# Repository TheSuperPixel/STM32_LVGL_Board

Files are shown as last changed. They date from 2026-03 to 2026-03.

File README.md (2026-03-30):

# STM32H750屏幕一体板
## 简介
这是我在2025年3月做的一个STM32H750屏幕一体开发板，板载SDRAM，QSPI FLASH，SD卡，DAP-LINK，LCD屏幕，OV5640摄像头。板子参考反客科技设计，可运行LVGL等多种图形化界面系统。

在2024学习完嵌入式Linux和FPGA后，我一直好奇板子的硬件电路结构和硬件设计，在好奇心的和网上各位开源大佬工程的熏陶下，我开始学习高速电路设计与layout。通过观看教程 我学习了高速PCB的设计技巧，BGA芯片的封装的扇孔布线技巧，传输线和计算阻抗匹配方法，蛇形等长和差分等长的绘制技巧，电源铺铜技巧，了解了电源拓扑，DDR拓扑结构和EMC电磁兼容的大致内容，板子制作过程碰到了很多困难，USB忘记串接电阻，LCD接口画反，错把无源晶振当有源晶振焊接造成电源短路，FLASH芯片型号选错，二极管封装画反等问题接连出现，在不断调整和改进下，板子的外设和LVGL终于全部跑通了！
## 演示视频
https://www.bilibili.com/video/BV1wXQhY8ENJ

## 使用方法
### 屏幕一体板v1 文件夹
第1版屏幕一体板的AD工程，已打板测试，阻抗不限，测试时在捷配进行打板<br>
此版本有LCD接口画反、USB信号线忘记上拉电阻导致无法通信、FLASH 芯片封装错误等问题，不建议使用。

### 屏幕一体板v2 文件夹
第2版屏幕一体板的AD工程，已打板测试，阻抗不限，测试时在捷配进行打板<br>
此版本改进上一版的问题，在焊接的时候因为在有源晶振位置错焊无源晶振，导致板子短路。后续重装主芯片和SDRAM后开始出现SDRAM读写失败的问题。此版本未经过充分测试，不建议使用。

### 屏幕一体板v3 文件夹
第3版屏幕一体板的AD工程，已打板测试，阻抗不限，测试时在捷配进行打板<br>
此版本在上一版的基础上，独立了各个外设电路的电源域，通过0欧姆电阻相连。后续发现3.3V电源不稳，导致有概率无法和电脑进行USB通信。经过排查初步判断因为输入的5V电源的滤波电容不够引起的。

### 测试例程
存放着测试例程代码，主要来自反客科技资料

### 其他资料
存放着DAP-LINK固件(推荐使用串口烧录)、调试时记录的《STM32H750屏幕一体板调试笔记》

## 主要参考资料
1.反客科技STM32H750XBH6板子 https://www.taobao.com/list/dianpu/212360197.htm<br>
2.CMSIS DAP LINK设计 https://oshwhub.com/Southerly/daplink-fang-zhen-qi-swd

## 注意事项
1.请严格遵守开源协议，若需要转载分享仓库内容，请注明来源。不得擅自将本设计用于商业用途。<br>
2.本项目仅供个人研究、学习与交流。元器件、封装、原理图和PCB设计等已根据数据手册重新校验或绘制。若您认为本项目中不慎包含了侵犯您版权的内容，请及时联系，我将第一时间予以处理。

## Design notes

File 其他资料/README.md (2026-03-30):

# 第三方资料声明

## 来源说明
CMSIS_DAP.hex文件来自 https://oshwhub.com/Southerly/daplink-fang-zhen-qi-swd

## 版权与协议 (Copyright & License)
* **版权归属：** 版权归原作者所有。
* **引用目的：** 本项目仅将其作为硬件验证的参考驱动使用。

## 免责声明
本项目作者 (TheSuperPixel) 不对本目录下的文件质量、稳定性或潜在侵权风险负责。

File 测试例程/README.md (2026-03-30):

# Third-Party Source Notice (第三方代码声明)
LVGL例程_基于800x480分辨率_窗口控件演示

## 来源说明
本目录下的代码及工程文件（包括但不限于底层驱动、寄存器配置、初始化脚本）由 **反客科技** 提供。

## 版权与协议
* **版权归属：** 版权归原作者所有。
* **引用目的：** 本项目仅将其作为硬件验证的参考驱动使用。

## 免责声明
本项目作者 (TheSuperPixel) 不对本目录下的代码质量、稳定性或潜在侵权风险负责。

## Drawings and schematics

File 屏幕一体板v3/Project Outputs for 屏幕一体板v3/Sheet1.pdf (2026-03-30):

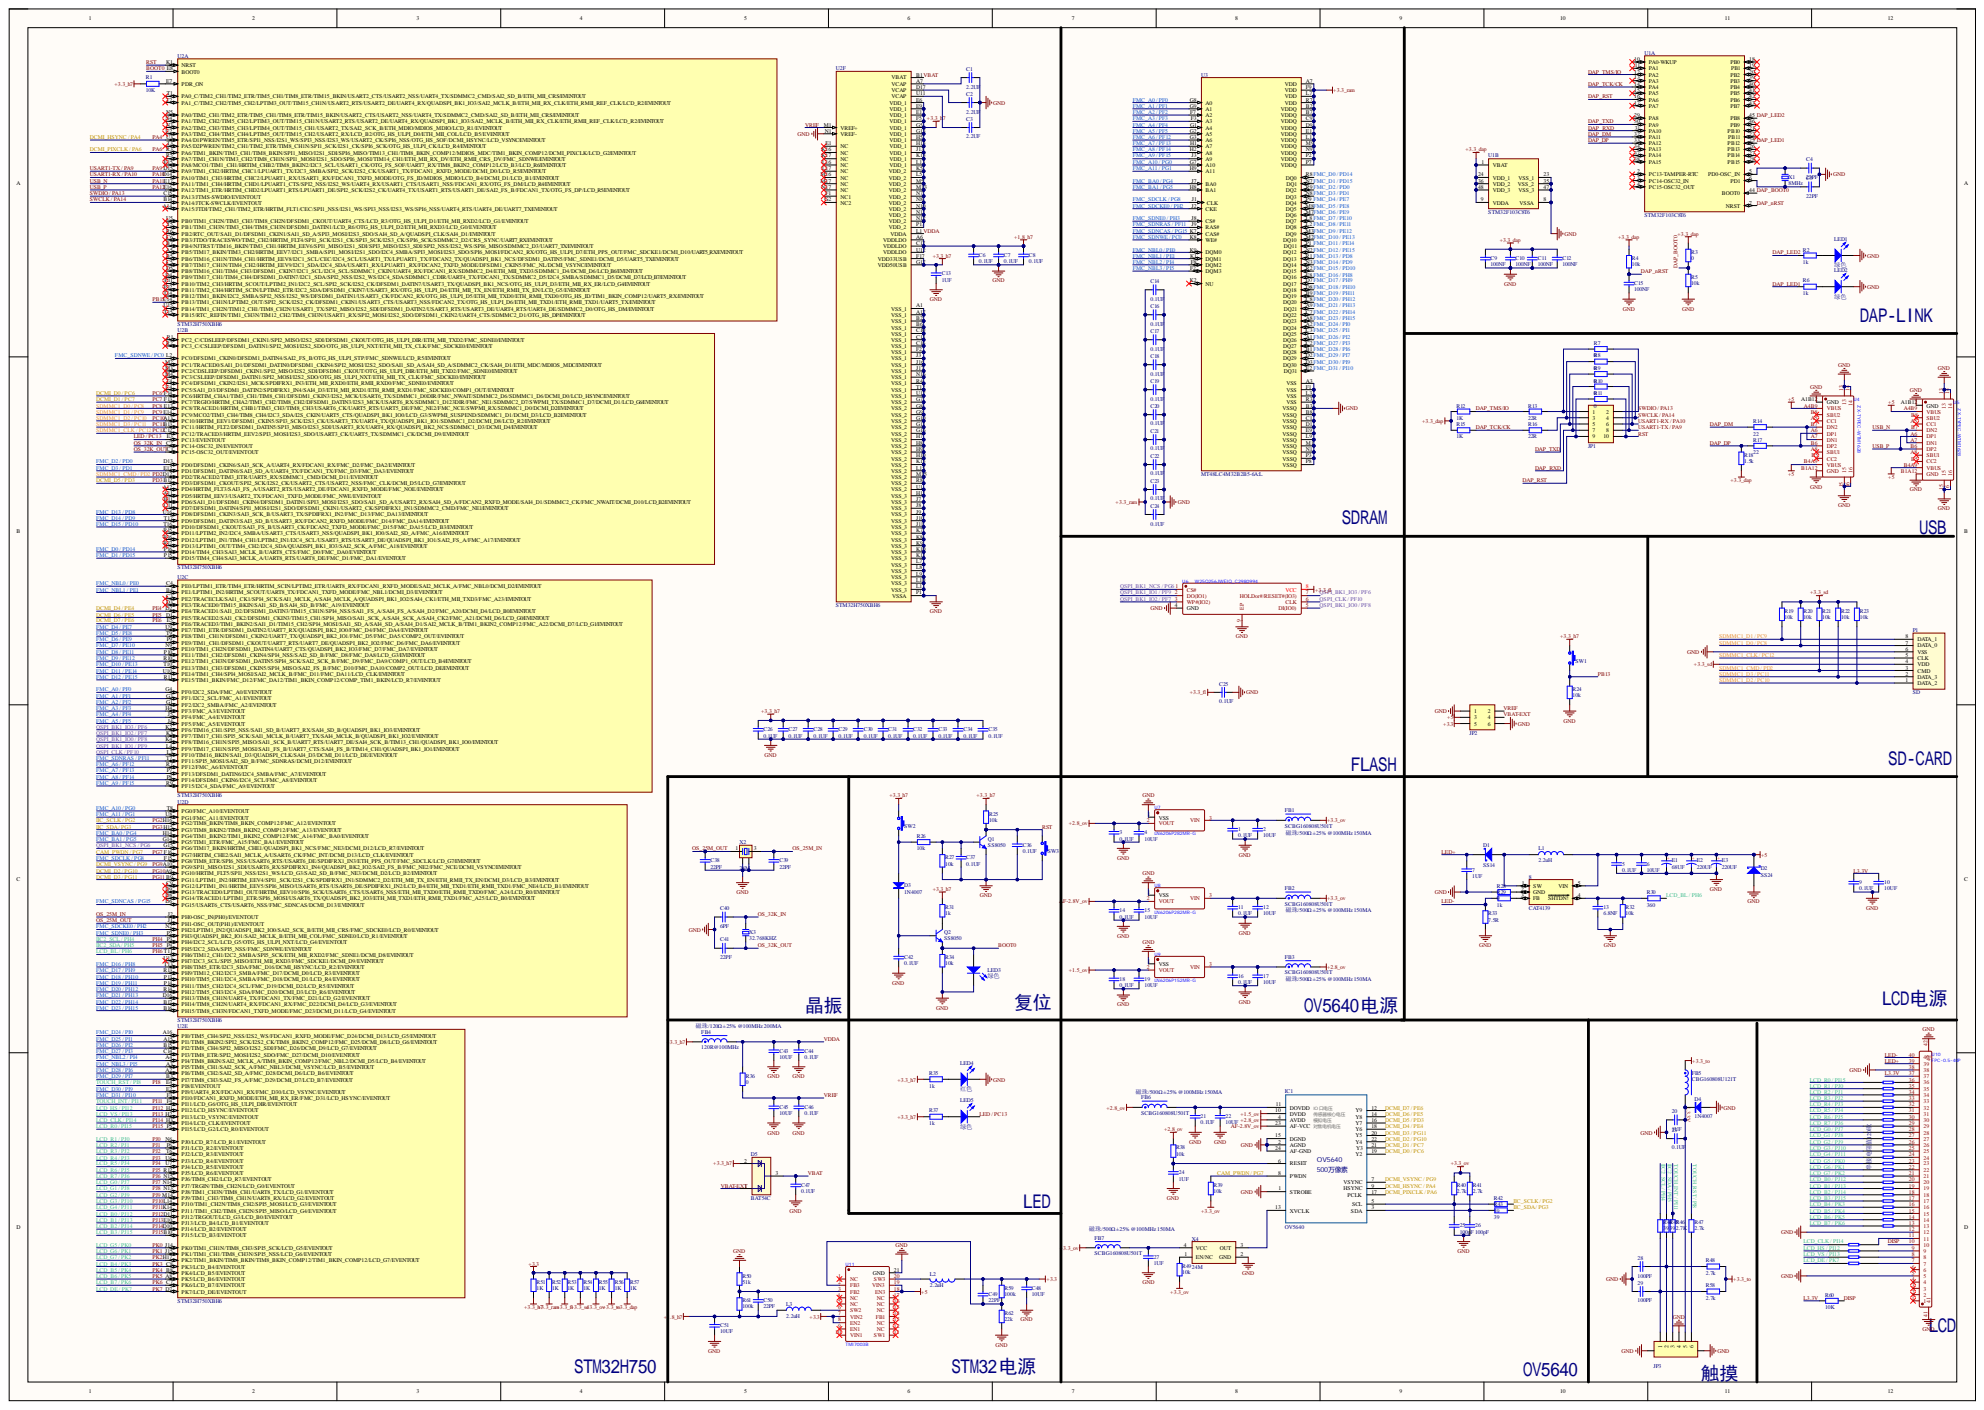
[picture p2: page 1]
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

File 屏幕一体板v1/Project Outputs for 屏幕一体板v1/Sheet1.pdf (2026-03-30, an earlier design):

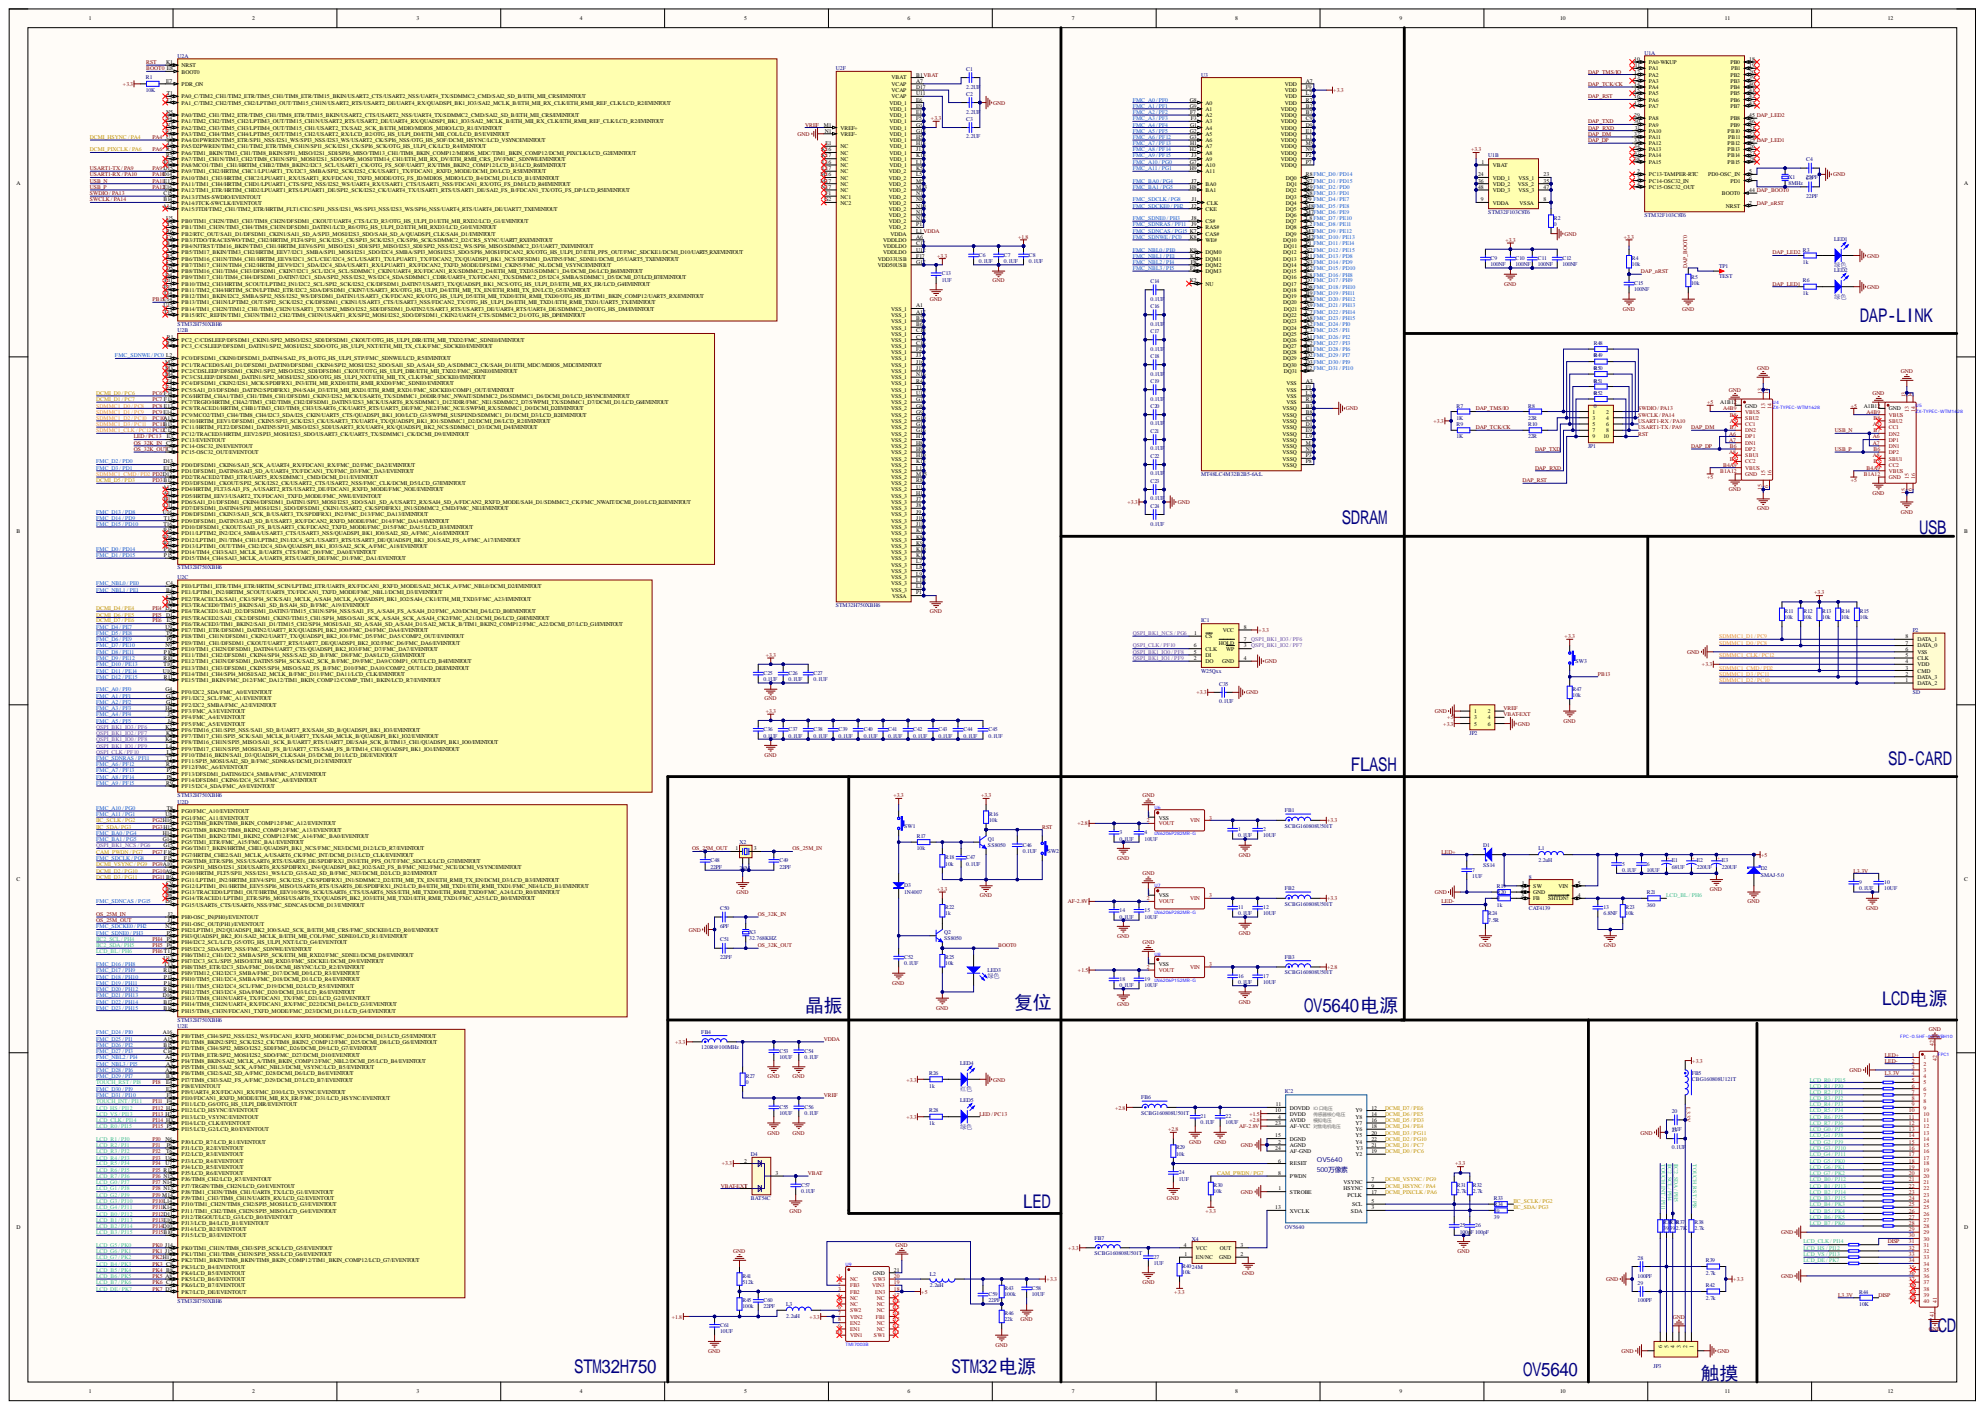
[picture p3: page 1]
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

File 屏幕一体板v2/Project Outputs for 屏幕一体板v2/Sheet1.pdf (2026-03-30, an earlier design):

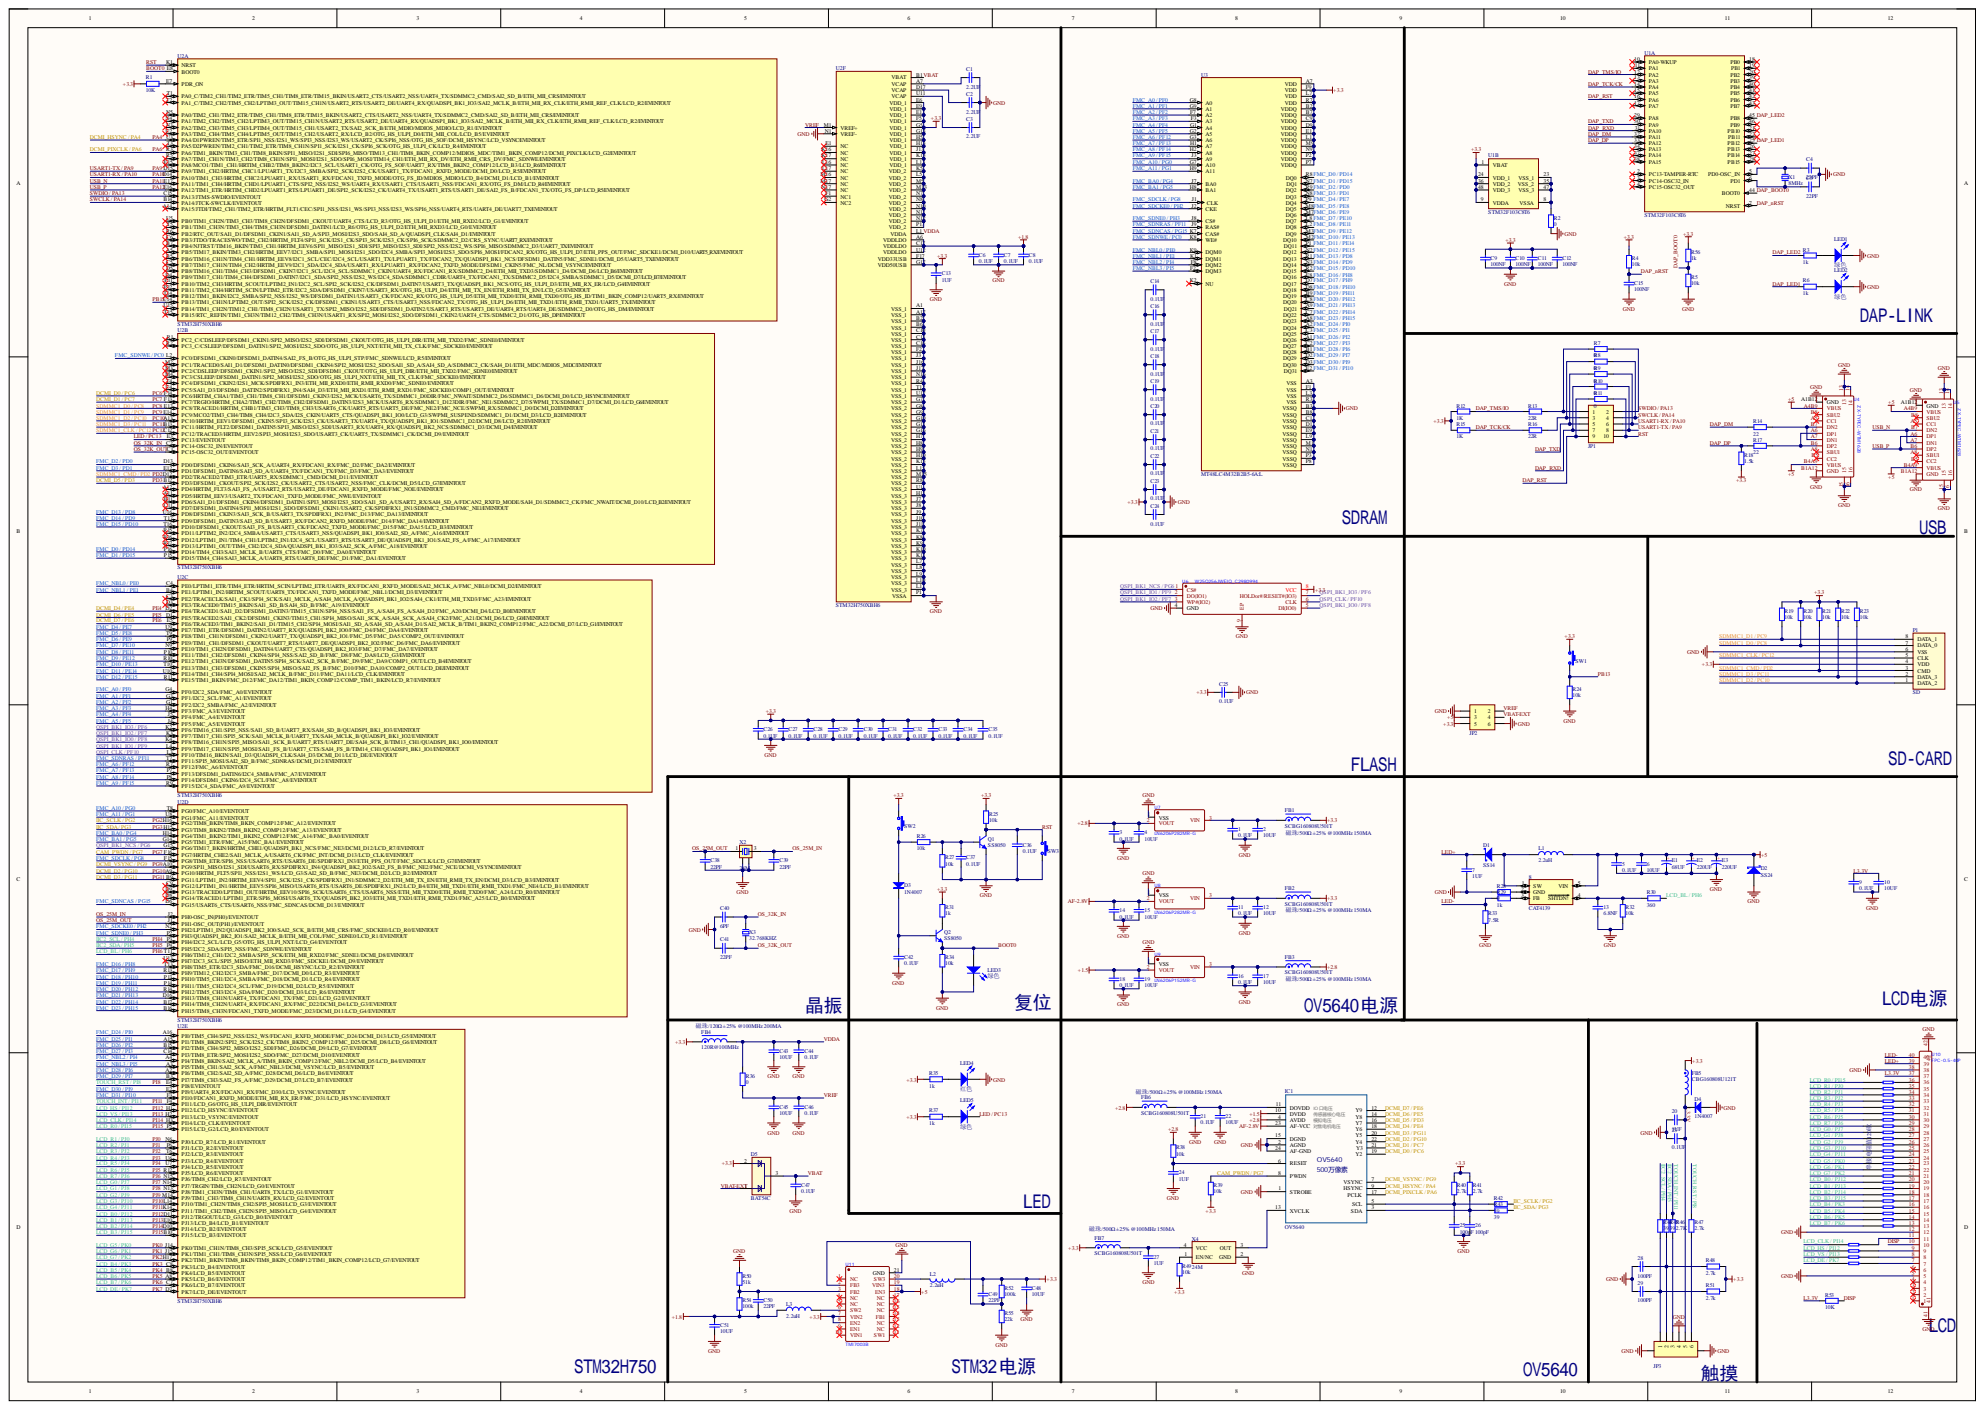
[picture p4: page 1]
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

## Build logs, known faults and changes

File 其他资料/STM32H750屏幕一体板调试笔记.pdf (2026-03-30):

# 屏幕一体板焊接和调试

## 2025.3 月左右完成

# 1.3.3V 短路问题

1.2.28 日，第一次打板，发现 3.3V 短路
原因：背面的去耦电容是 0201 封装，但是焊接了 0402 封装造成连锡

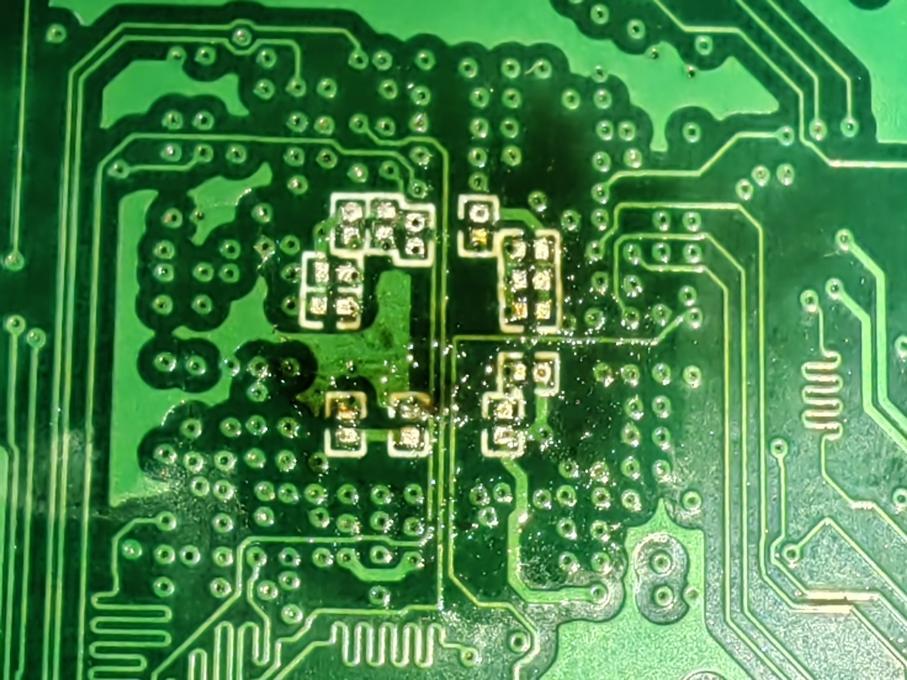
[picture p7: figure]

## 2.FLASH 芯片读写错误问题

2.2.28 日，第一次打板，发现 FLASH 芯片读写错误

## 原因：把 W25Q256 买成了 W25Q32

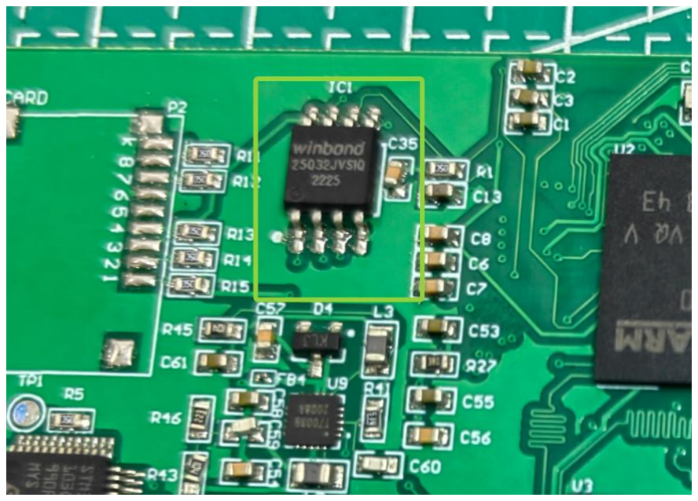
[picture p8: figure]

## 3.电脑无法连接 USB 问题

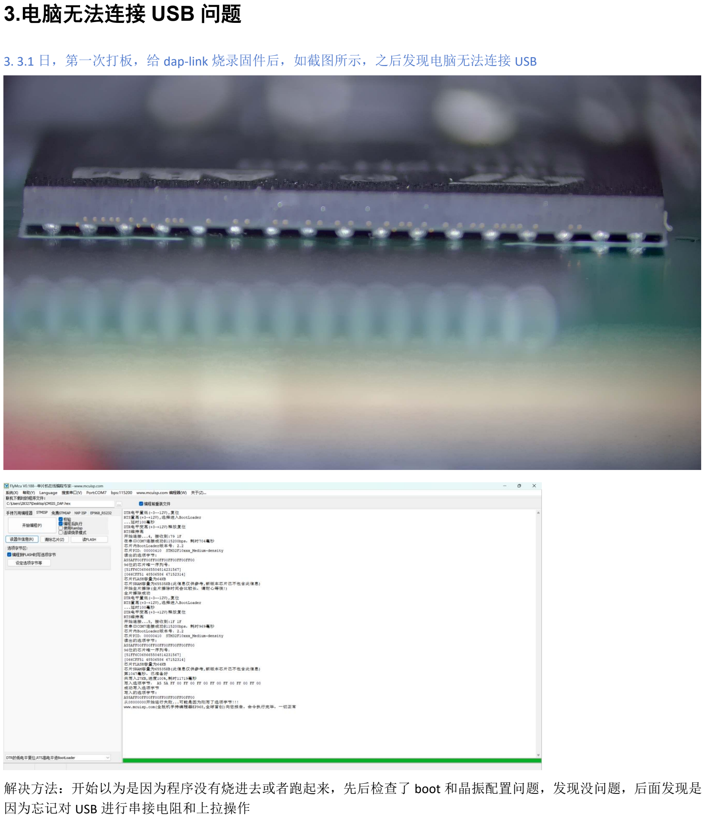
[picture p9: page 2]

3. 3.1 日，第一次打板，给 dap-link 烧录固件后，如截图所示，之后发现电脑无法连接 USB

解决方法：开始以为是因为程序没有烧进去或者跑起来，先后检查了 boot 和晶振配置问题，发现没问题，后面发现是 因为忘记对 USB 进行串接电阻和上拉操作

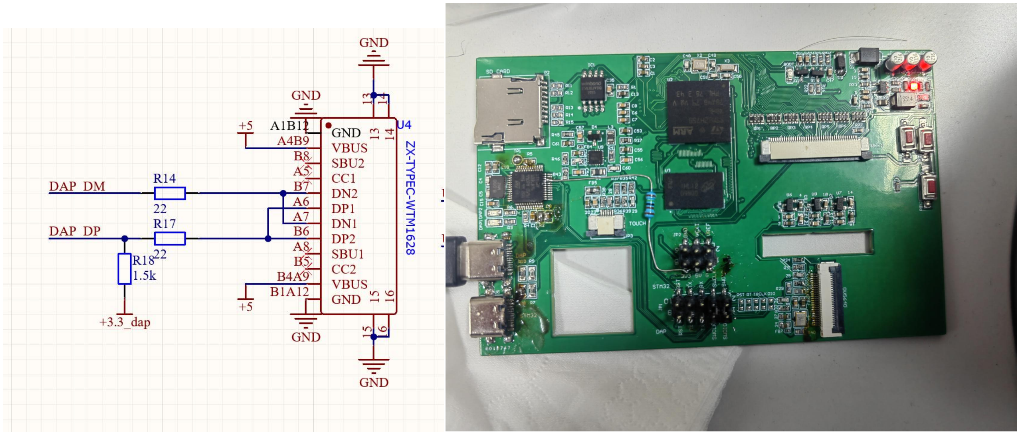
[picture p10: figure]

## 4.LCD 接口画反问题

4. 3.1 日左右，第一次打板，发现 LCD 接口画反 解决方法：重画 LCD 电路

# 5.3.3V 和 GND 短路问题

5. 3.8 日左右，第二次打板，焊接主芯片后，发现 3.3V 和 GND 短路，拆除主芯片,SDRAM，DAP-LINK 后还是短路 原因：摄像头的有源晶振焊成了无源晶振造成短路，而第一次打板的时候因为连接晶振的磁珠是 0201 的，焊接的时候 虚焊了，晶振没有通电，因此第二次打板的时候问题才显露，直到我尝试割断摄像头电源的铜皮时才发现原因 解决方法：增加电源 DEBUG 电路

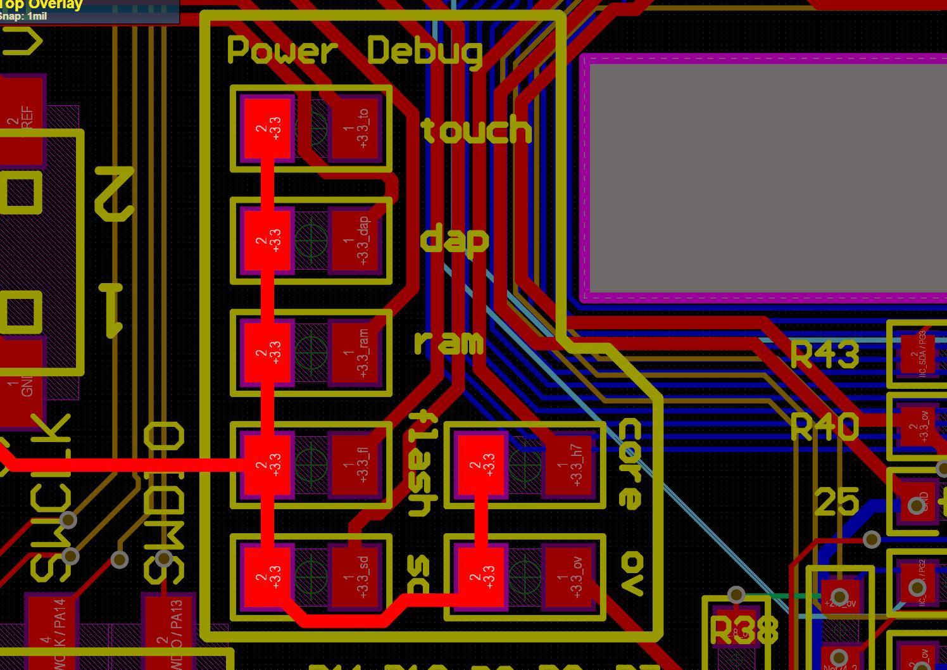
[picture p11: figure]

# 6.SDRAM 测试失败问题

6.3.12 日左右，第二次打板，重新焊接主芯片的 SDRAM，结果 SDRAM 测试失败

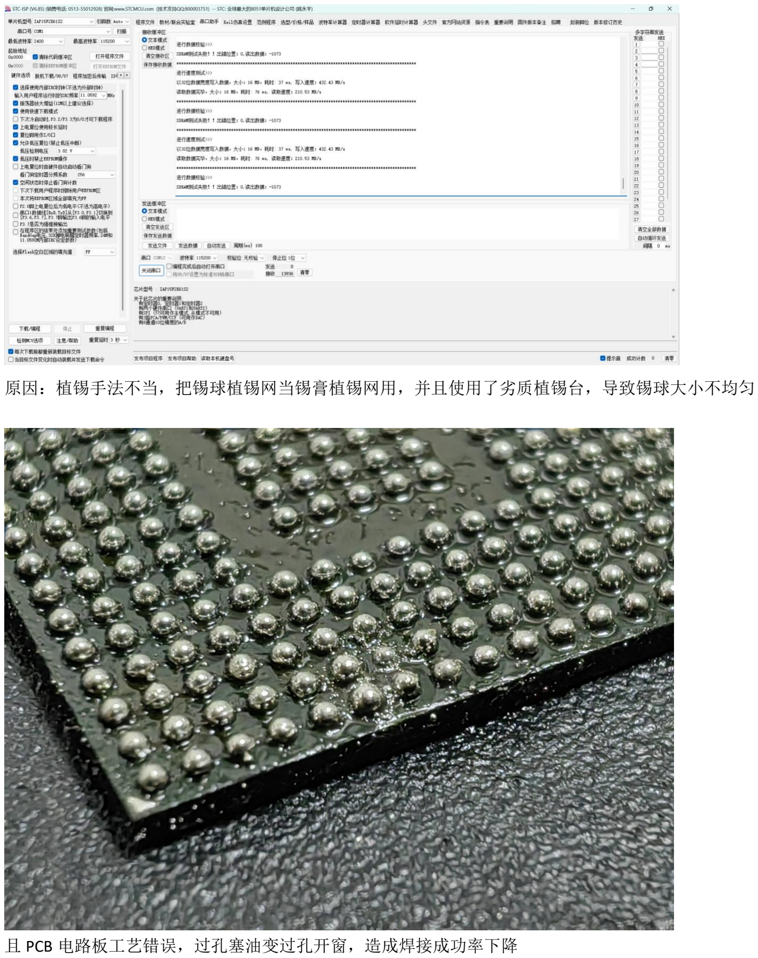
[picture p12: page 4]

原因：植锡手法不当，把锡球植锡网当锡膏植锡网用，并且使用了劣质植锡台，导致锡球大小不均匀

且 PCB 电路板工艺错误，过孔塞油变过孔开窗，造成焊接成功率下降

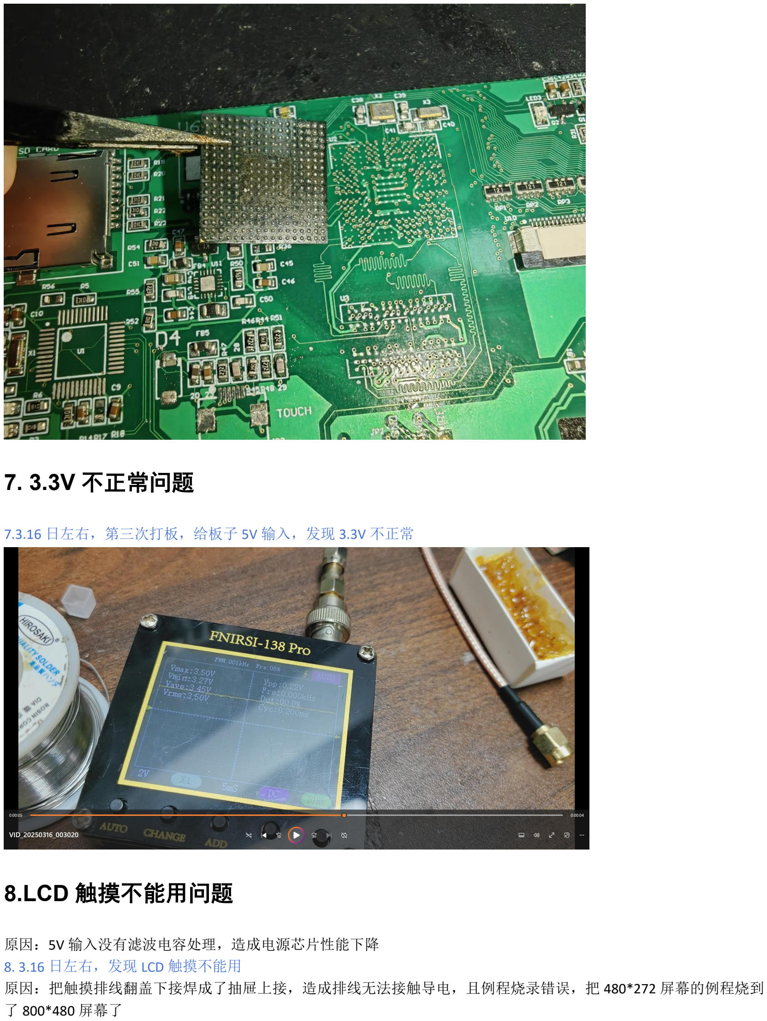
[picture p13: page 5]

# 7. 3.3V 不正常问题

7.3.16 日左右，第三次打板，给板子 5V 输入，发现 3.3V 不正常

## 8.LCD 触摸不能用问题

原因：5V 输入没有滤波电容处理，造成电源芯片性能下降
8. 3.16 日左右，发现 LCD 触摸不能用
原因：把触摸排线翻盖下接焊成了抽屉上接，造成排线无法接触导电，且例程烧录错误，把 480*272 屏幕的例程烧到

## 了 800*480 屏幕了

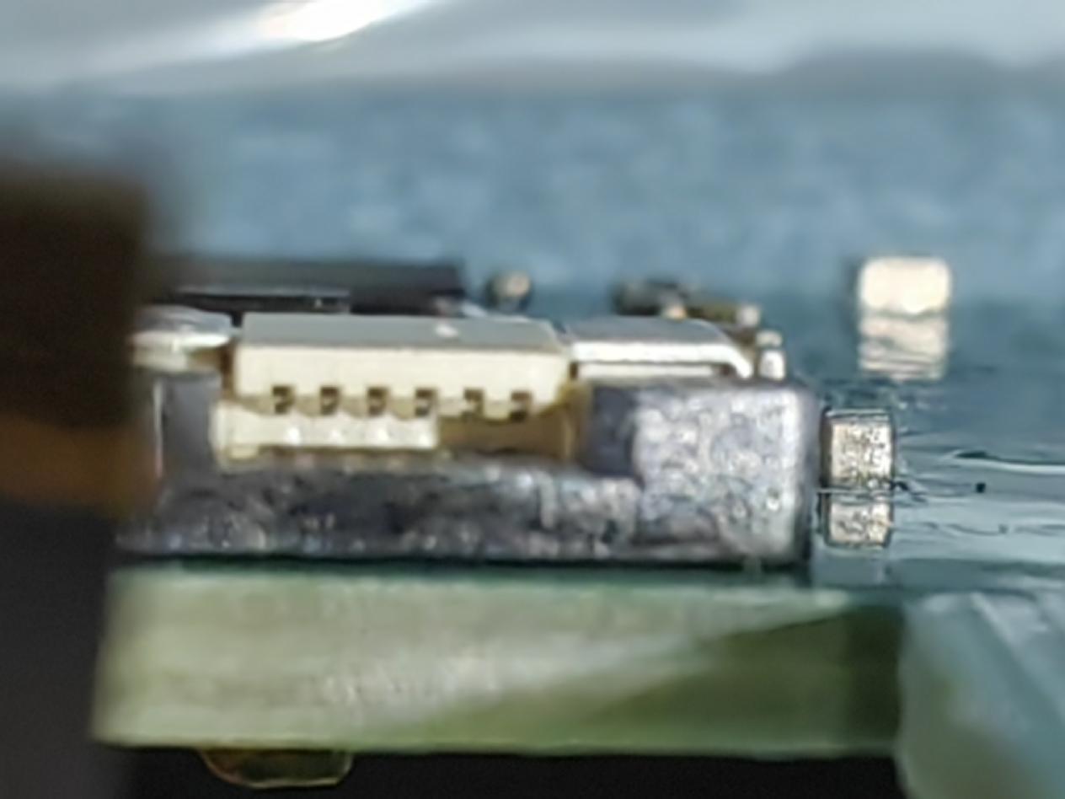
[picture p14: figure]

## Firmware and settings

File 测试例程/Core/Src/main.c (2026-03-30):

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
/* Includes ------------------------------------------------------------------*/
#include "main.h"
#include "cmsis_os.h"

/* USER CODE BEGIN Includes */
#include "led.h"
#include "usart.h"
#include "sdram.h"  
#include "lcd_rgb.h"
#include "touch_800x480.h"
#include "lvgl.h"
#include "lv_port_disp_template.h"
#include "lv_port_indev_template.h"
#include "lv_demo_widgets.h"
/* USER CODE END Includes */


DMA2D_HandleTypeDef hdma2d;

LTDC_HandleTypeDef hltdc;

UART_HandleTypeDef huart1;

SDRAM_HandleTypeDef hsdram1;

/* Definitions for defaultTask */
osThreadId_t defaultTaskHandle;
const osThreadAttr_t defaultTask_attributes = {
  .name = "defaultTask",
  .stack_size = 2048 * 4,
  .priority = (osPriority_t) osPriorityNormal,
};
/* Definitions for ledTask02 */
osThreadId_t ledTask02Handle;
const osThreadAttr_t ledTask02_attributes = {
  .name = "ledTask02",
  .stack_size = 128 * 4,
  .priority = (osPriority_t) osPriorityLow,
};
/* Definitions for uartTask03 */
osThreadId_t uartTask03Handle;
const osThreadAttr_t uartTask03_attributes = {
  .name = "uartTask03",
  .stack_size = 1024 * 4,
  .priority = (osPriority_t) osPriorityLow,
};
/* USER CODE BEGIN PV */
osMutexId_t mutex_id;

const osMutexAttr_t Thread_Mutex_attr = {
  "myThreadMutex",     // human readable mutex name
  osMutexPrioInherit,  // attr_bits
  NULL,                // memory for control block   
  0U                   // size for control block
};

/* USER CODE END PV */

void SystemClock_Config(void);
static void MPU_Config(void);
static void MX_GPIO_Init(void);
static void MX_USART1_UART_Init(void);
static void MX_FMC_Init(void);
static void MX_DMA2D_Init(void);
static void MX_LTDC_Init(void);
void StartDefaultTask(void *argument);
void StartTask02(void *argument);
void StartTask03(void *argument);

/**
  * @brief  The application entry point.
  * @retval int
  */
int main(void)
{
  /* MPU Configuration--------------------------------------------------------*/
  MPU_Config();
/* Enable the CPU Cache */

  /* Enable I-Cache---------------------------------------------------------*/
  SCB_EnableICache();

  /* Enable D-Cache---------------------------------------------------------*/
  SCB_EnableDCache();

  /* MCU Configuration--------------------------------------------------------*/

  /* Reset of all peripherals, Initializes the Flash interface and the Systick. */
  HAL_Init();

  /* Configure the system clock */
  SystemClock_Config();

  /* Initialize all configured peripherals */
  MX_GPIO_Init();
  MX_USART1_UART_Init();
  MX_FMC_Init();
  MX_DMA2D_Init();
  MX_LTDC_Init();
  /* USER CODE BEGIN 2 */
	LED_Init();					// 初始化LED引脚
	SDRAM_Initialization_Sequence(&hsdram1);	// 配置SDRAM相关时序和控制方式
	
	LCD_RGB_Init();		// 初始化屏幕
	Touch_Init();				// 触摸屏初始化		
	
  /* USER CODE END 2 */

  /* Init scheduler */
  osKernelInitialize();

  /* USER CODE BEGIN RTOS_MUTEX */
  /* add mutexes, ... */
  /* USER CODE END RTOS_MUTEX */

  /* USER CODE BEGIN RTOS_SEMAPHORES */
  /* add semaphores, ... */
  /* USER CODE END RTOS_SEMAPHORES */

  /* USER CODE BEGIN RTOS_TIMERS */
  /* start timers, add new ones, ... */
  /* USER CODE END RTOS_TIMERS */

  /* USER CODE BEGIN RTOS_QUEUES */
  /* add queues, ... */
  /* USER CODE END RTOS_QUEUES */

  /* Create the thread(s) */
  /* creation of defaultTask */
  defaultTaskHandle = osThreadNew(StartDefaultTask, NULL, &defaultTask_attributes);

  /* creation of ledTask02 */
  ledTask02Handle = osThreadNew(StartTask02, NULL, &ledTask02_attributes);

  /* creation of uartTask03 */
  uartTask03Handle = osThreadNew(StartTask03, NULL, &uartTask03_attributes);

  /* USER CODE BEGIN RTOS_THREADS */
  /* add threads, ... */
 	mutex_id = osMutexNew(&Thread_Mutex_attr);
	   
  
  /* USER CODE END RTOS_THREADS */

  /* USER CODE BEGIN RTOS_EVENTS */
  /* add events, ... */
  /* USER CODE END RTOS_EVENTS */

  /* Start scheduler */
  osKernelStart();

  /* We should never get here as control is now taken by the scheduler */
  /* Infinite loop */
  /* USER CODE BEGIN WHILE */
  
  
  while (1)
  {
    /* USER CODE END WHILE */

    /* USER CODE BEGIN 3 */
	  	  
  }
  /* USER CODE END 3 */
}

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
/* USER CODE BEGIN Header_StartDefaultTask */
/**
  * @brief  Function implementing the defaultTask thread.
  * @param  argument: Not used
  * @retval None
  */
/* USER CODE END Header_StartDefaultTask */
void StartDefaultTask(void *argument)
{
  /* USER CODE BEGIN 5 */
	uint32_t  time;

	lv_init();					//	LVGL初始化
	lv_port_disp_init();		//	LVGL显示接口初始化
	lv_port_indev_init();	// LVGL触摸接口初始化		
	
	lv_demo_widgets();   // 运行官方例程 lv_demo_benchmark ，进行基准性能测试			
	
  /* Infinite loop */
  for(;;)
  {
		osMutexAcquire(mutex_id, osWaitForever);
		
		lv_task_handler();	// 如果在多任务中需要进行LVGL相关操作，需要考虑加互斥锁，具体可以参考LVGL官方的介绍

		osMutexRelease(mutex_id);
	  
	  	Touch_Scan();	// 触摸扫描
				
		osDelay(LV_DISP_DEF_REFR_PERIOD);	// 延时不能小于 LV_DISP_DEF_REFR_PERIOD，否则会闪烁，另外触摸扫描的延时也不能太低			  
  }
  /* USER CODE END 5 */
}

/* USER CODE BEGIN Header_StartTask02 */
/**
* @brief Function implementing the ledTask02 thread.
* @param argument: Not used
* @retval None
*/
/* USER CODE END Header_StartTask02 */
void StartTask02(void *argument)
{
  /* USER CODE BEGIN StartTask02 */
  /* Infinite loop */
  for(;;)
  {
	  LED1_Toggle;
     osDelay(100);
  }
  /* USER CODE END StartTask02 */
}

/* USER CODE BEGIN Header_StartTask03 */
/**
* @brief Function implementing the uartTask03 thread.
* @param argument: Not used
* @retval None
*/
/* USER CODE END Header_StartTask03 */
void StartTask03(void *argument)
{
  /* USER CODE BEGIN StartTask03 */
  /* Infinite loop */
  for(;;)
  {
		osDelay(10);
  }
  /* USER CODE END StartTask03 */
}

/* MPU Configuration */

void MPU_Config(void)
{
  MPU_Region_InitTypeDef MPU_InitStruct = {0};

  /* Disables the MPU */
  HAL_MPU_Disable();

  /** Initializes and configures the Region and the memory to be protected
  */
  MPU_InitStruct.Enable = MPU_REGION_ENABLE;
  MPU_InitStruct.Number = MPU_REGION_NUMBER0;
  MPU_InitStruct.BaseAddress = 0xC0000000;
  MPU_InitStruct.Size = MPU_REGION_SIZE_16MB;
  MPU_InitStruct.SubRegionDisable = 0x0;
  MPU_InitStruct.TypeExtField = MPU_TEX_LEVEL0;
  MPU_InitStruct.AccessPermission = MPU_REGION_FULL_ACCESS;
  MPU_InitStruct.DisableExec = MPU_INSTRUCTION_ACCESS_ENABLE;
  MPU_InitStruct.IsShareable = MPU_ACCESS_NOT_SHAREABLE;
  MPU_InitStruct.IsCacheable = MPU_ACCESS_CACHEABLE;
  MPU_InitStruct.IsBufferable = MPU_ACCESS_NOT_BUFFERABLE;

  HAL_MPU_ConfigRegion(&MPU_InitStruct);
  /* Enables the MPU */
  HAL_MPU_Enable(MPU_PRIVILEGED_DEFAULT);

}

/**
  * @brief  Period elapsed callback in non blocking mode
  * @note   This function is called  when TIM17 interrupt took place, inside
  * HAL_TIM_IRQHandler(). It makes a direct call to HAL_IncTick() to increment
  * a global variable "uwTick" used as application time base.
  * @param  htim : TIM handle
  * @retval None
  */
void HAL_TIM_PeriodElapsedCallback(TIM_HandleTypeDef *htim)
{
  if (htim->Instance == TIM17) {
    HAL_IncTick();
  }
}

/**
  * @brief  This function is executed in case of error occurrence.
  * @retval None
  */
void Error_Handler(void)
{
  /* USER CODE BEGIN Error_Handler_Debug */
  /* User can add his own implementation to report the HAL error return state */
  __disable_irq();
  while (1)
  {
  }
  /* USER CODE END Error_Handler_Debug */
}

#ifdef  USE_FULL_ASSERT
/**
  * @brief  Reports the name of the source file and the source line number
  *         where the assert_param error has occurred.
  * @param  file: pointer to the source file name
  * @param  line: assert_param error line source number
  * @retval None
  */
void assert_failed(uint8_t *file, uint32_t line)
{
  /* USER CODE BEGIN 6 */
  /* User can add his own implementation to report the file name and line number,
     ex: printf("Wrong parameters value: file %s on line %d\r\n", file, line) */
  /* USER CODE END 6 */
}
#endif /* USE_FULL_ASSERT */

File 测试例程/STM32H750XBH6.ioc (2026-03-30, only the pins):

Mcu.UserName=STM32H750XBHx
PA10.Signal=USART1_RX
PA9.Signal=USART1_TX
PC0.Signal=FMC_SDNWE
PD0.Signal=FMC_D2_DA2
PD1.Signal=FMC_D3_DA3
PD10.Signal=FMC_D15_DA15
PD14.Signal=FMC_D0_DA0
PD15.Signal=FMC_D1_DA1
PD8.Signal=FMC_D13_DA13
PD9.Signal=FMC_D14_DA14
PE0.Signal=FMC_NBL0
PE1.Signal=FMC_NBL1
PE10.Signal=FMC_D7_DA7
PE11.Signal=FMC_D8_DA8
PE12.Signal=FMC_D9_DA9
PE13.Signal=FMC_D10_DA10
PE14.Signal=FMC_D11_DA11
PE15.Signal=FMC_D12_DA12
PE7.Signal=FMC_D4_DA4
PE8.Signal=FMC_D5_DA5
PE9.Signal=FMC_D6_DA6
PF0.Signal=FMC_A0
PF1.Signal=FMC_A1
PF11.Signal=FMC_SDNRAS
PF12.Signal=FMC_A6
PF13.Signal=FMC_A7
PF14.Signal=FMC_A8
PF15.Signal=FMC_A9
PF2.Signal=FMC_A2
PF3.Signal=FMC_A3
PF4.Signal=FMC_A4
PF5.Signal=FMC_A5
PG0.Signal=FMC_A10
PG1.Signal=FMC_A11
PG15.Signal=FMC_SDNCAS
PG4.Signal=FMC_A14_BA0
PG5.Signal=FMC_A15_BA1
PG8.Signal=FMC_SDCLK
PH10.Signal=FMC_D18
PH11.Signal=FMC_D19
PH12.Signal=FMC_D20
PH13.Signal=FMC_D21
PH14.Signal=FMC_D22
PH15.Signal=FMC_D23
PH2.Signal=FMC_SDCKE0
PH3.Signal=FMC_SDNE0
PH8.Signal=FMC_D16
PH9.Signal=FMC_D17
PI0.Signal=FMC_D24
PI1.Signal=FMC_D25
PI10.Signal=FMC_D31
PI12.Signal=LTDC_HSYNC
PI13.Signal=LTDC_VSYNC
PI14.Signal=LTDC_CLK
PI15.Signal=LTDC_R0
PI2.Signal=FMC_D26
PI3.Signal=FMC_D27
PI4.Signal=FMC_NBL2
PI5.Signal=FMC_NBL3
PI6.Signal=FMC_D28
PI7.Signal=FMC_D29
PI9.Signal=FMC_D30
PJ0.Signal=LTDC_R1
PJ1.Signal=LTDC_R2
PJ10.Signal=LTDC_G3
PJ11.Signal=LTDC_G4
PJ12.Signal=LTDC_B0
PJ13.Signal=LTDC_B1
PJ14.Signal=LTDC_B2
PJ15.Signal=LTDC_B3
PJ2.Signal=LTDC_R3
PJ3.Signal=LTDC_R4
PJ4.Signal=LTDC_R5
PJ5.Signal=LTDC_R6
PJ6.Signal=LTDC_R7
PJ7.Signal=LTDC_G0
PJ8.Signal=LTDC_G1
PJ9.Signal=LTDC_G2
PK0.Signal=LTDC_G5
PK1.Signal=LTDC_G6
PK2.Signal=LTDC_G7
PK3.Signal=LTDC_B4
PK4.Signal=LTDC_B5
PK5.Signal=LTDC_B6
PK6.Signal=LTDC_B7
PK7.Signal=LTDC_DE

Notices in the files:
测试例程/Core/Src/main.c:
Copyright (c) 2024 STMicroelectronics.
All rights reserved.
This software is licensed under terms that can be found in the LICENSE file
